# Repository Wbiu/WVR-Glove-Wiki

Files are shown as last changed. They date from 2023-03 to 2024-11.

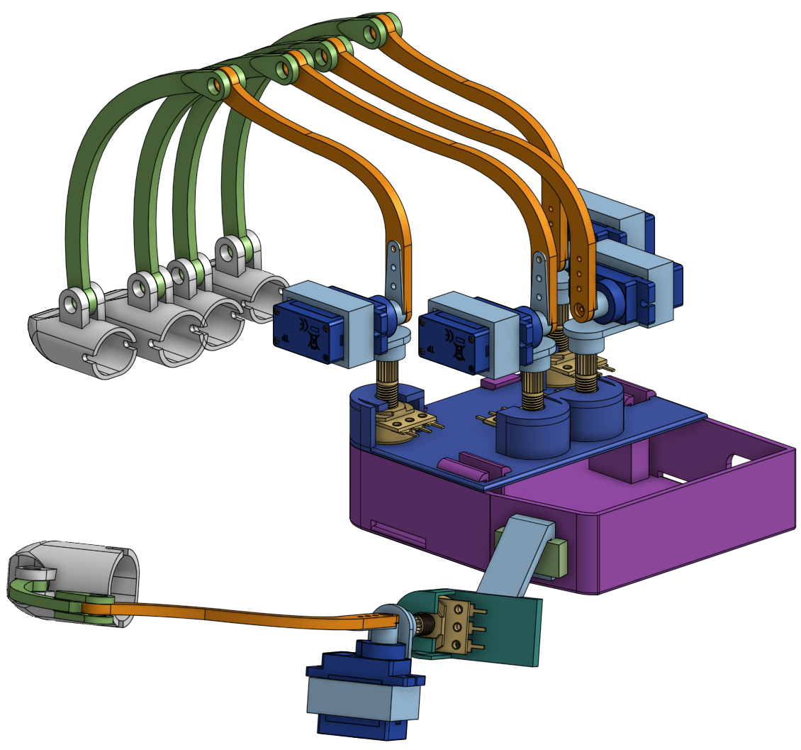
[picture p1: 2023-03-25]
Glove_STL/oneShape_model_v1.PNG

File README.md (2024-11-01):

# WVR Glove Wiki
## Let´s start building the glove
### Things that you will need before we start building.

> **note** : I´m assuming that you have some basic stuff before hand 
> such as soldering equipment, 3D printer and some tools ... <br/>
> Also some knowledge in C++ would help you a bit.

> **info** : for newbies this could be a bit tough. I was thinking about doing a youtube tutorial. For that please vote in [discord](https://discord.gg/FY35dYT8) in the vote chanel, if there is an interest for a video. 

* esp32 (wroom/wrover) Dev-board (I´m recommending that you get 2 of them )
* 1x 9 axis IMU (in this project a BNO055 was used)
* 5x sg90 Servos (this has to be some specific ons. see more in **modding servo**)
* 5x B10K [Potentiometer](https://www.amazon.com/TELESKY-Linear-Potentiometer-Variable-Resistors/dp/B09T32L928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) (also get them with some washer and nuts)
* some prototype pcb board (a 5x7 should be enough) <br/>
* bread board for testing purposes
#### optional stuff , but also recommended to have :
* 5x (10x) jst connector 5 pin both male (5x) and female (5x) (if you don't own any of it a jst tool kit would help you out)
* I also use **TPU** for printing the fingertips.

## Printing the parts
Download the part from [this wiki](https://github.com/Wbiu/WVR-Glove-Wiki) repo.

## Modding SG90 servos
> **note** : This part could be somewhat complicated if you haven't work much in electronics. **But** it's not impossible. So let's go...

First **make sure** you get the right servo. What I mean by that is there are some **internal** differences depending on where you get them. 

What you will need is a servo with **2 chips** in it! <br/>
Next is to look up the part number on google. If google says that it is a **H-Bridge**  or a **H-Bridge motor control** then you are on the right track!  <br/>
In my case the **H-Bridge** is **TC8301**s and sometimes there could also  **TC118**s.

TC8310 servo

Now if we take a look at the data sheet of the **TC8301**. In the data sheet there is an example circuit diagram.
And we can see that pin **2** and **3** are labeled as input **A** and **B**.
With these 2 pins we can control the **speed** and **direction** with a **PWM** signal.  

tc8301 circuit

Here is how we can control the motors **speed** and **direction**. Later on we control these input with a PWM signal.<br/> L = low <br/>
H = high<br/>
TC8301 mode

In theory you can solder on the wires directly on the **TC8301** pins. A wire to INA and also a wire to INB, then also a wire to the middle pin of the potentiometer.
The yellow wire is no longer needed and can be removed.

And now you will have 5 wires attach to your servo. 
* INA wire
* INB wire 
* Potentiometer middle pin
* +VDD
* -GND

In my case I didn't do it that way. I flipped the PCB around and remove the other chip ("servo controller IC"). After some measuring I found out that there are pads connected to the **H-Bridge**. So I connected my wires there. But an additional wire connection is needed.
And of course there should be 5 wires coming out of the servo. 

> **tip** : take a note to your connected wires.
> And make **sure** that you cut a bigger exit for all the wires. 

> **caution!!** : there could be is a small extrusion/tip to prevent the servo from spinning 360°. This needs to be removed!

modded Servo
> **note** : picture is mirrored/flipped <br/>
>Servo Pos = Potentiometer middle pin

## Preparing the ESP32
Get visual studio code and install plattformio.
Download the [firmware](https://github.com/Wbiu/WVR-GLOVE-Firmware) and add it to plattformio.<br/>
PlattformIO : Home>Projects>Add Existing

> **note** : The default serial baud rate in the firmware is set to 250000.<br/>
> This can be changed in src/Properties.h under ``#define BAUDRATE`` 

Now just compile and upload the firmware to the esp32 to the right COM port with a baud rate of 115200. <br/>

> **note** : if you haven't changed the baud rate in the firmware please remember that you need set the baud rate in the serial monitor to 250000.

If you open up a serial monitor it should print out **" initialization error "** because no component are connected at the moment.

## Wiring 
Here is how every thing is wired internally.<br/>
I'm recommending that you prewire every thing on the breadboard first.<br/>
The IMU I'm using is the BNO055 from Adafruit.
internal wiringpng

## Testing
Now let's do some testing before you build the actual glove.
If every thing is connected correctly it should say **" initialize successful "** after boot up and you will get a lot of values that look somewhat like this.<br/>
data_out_esp

And to test whatever the servo has been successfully modded you can send ``120;0;0;0;0`` to the eso32. This will turn on the the **thumb servo**. Or if you send ``-120;0;0;0;0`` then servo will turn the other way around. The larger the value, the faster it becomes. Max value is ``255``. The value for turning off the servo is ``0;0;0;0;0``. 
> **note** : **thumb** ; **index** ; **middle** ; **ring** ; **pinky**

You can also hold the position reading process with ```#hold``` then the output should pause.
To continue just send ```#continue``` then the position reading process should resume.

## Configuration
To configure the glove I've wrote an aplicatoion for this.
See [here](https://github.com/Wbiu/WVR-Glove-Configurator).

## Additional connection

To keep every thing nice and tight. I made a adapter board with JSTs, to put on top of the esp32.
esp_adapterboard
serco_jst

## Final look

oneShape_model_v1

## Unreal Engine testing ground
After all the hard work let's test the glove in [Unreal Engine](https://github.com/Wbiu/WVR-Glove-Unreal-Engine-5.1-testing-ground) which I've built from the ground for this project. 
UE5 Greif Test _Trim

## Support
 If you want you can join my [discord](https://discord.gg/TnM6WXtwfb) server if there is any issues or questions.

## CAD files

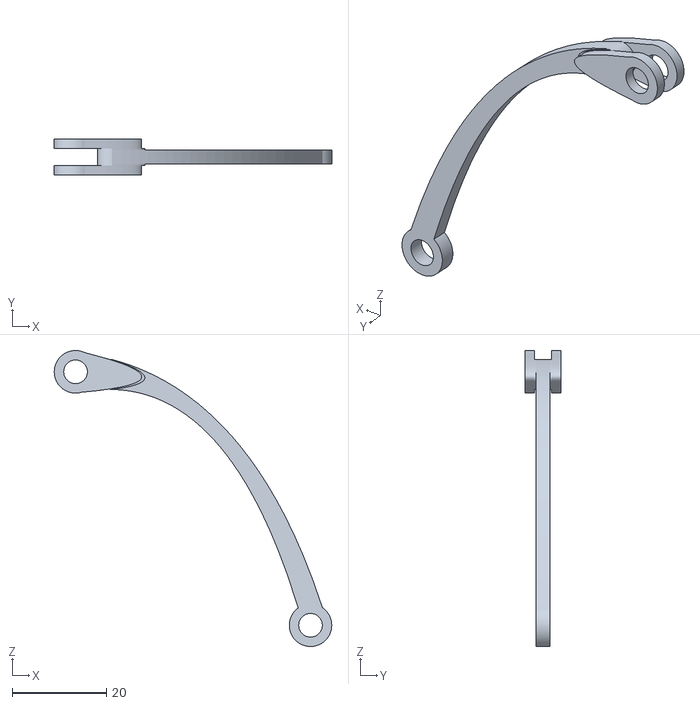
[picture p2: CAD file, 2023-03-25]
Glove_STL/finger arms/Finger arm thumb.stl
58.8 x 7.60 x 62.7

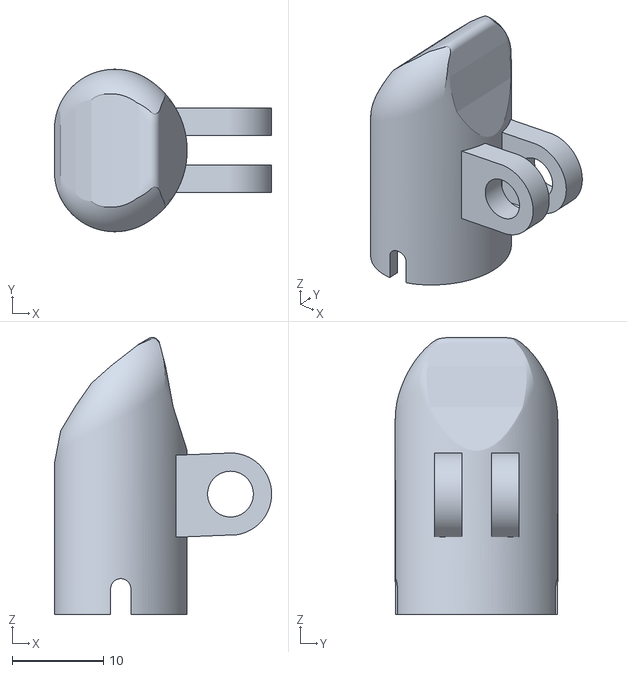
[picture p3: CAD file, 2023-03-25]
Glove_STL/finger tips size/index and ring/Index-Ring Tip_S.stl
23.8 x 17.8 x 30.3

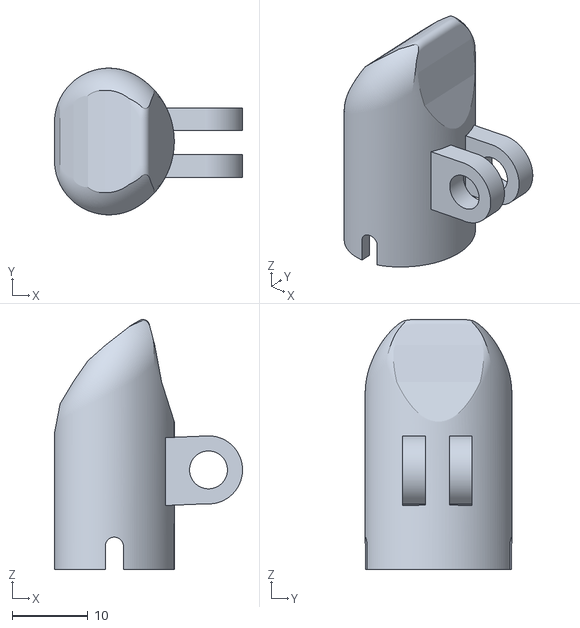
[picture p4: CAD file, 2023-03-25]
Glove_STL/finger tips size/middle/Middle Tip_S.stl
24.9 x 19.4 x 33.0

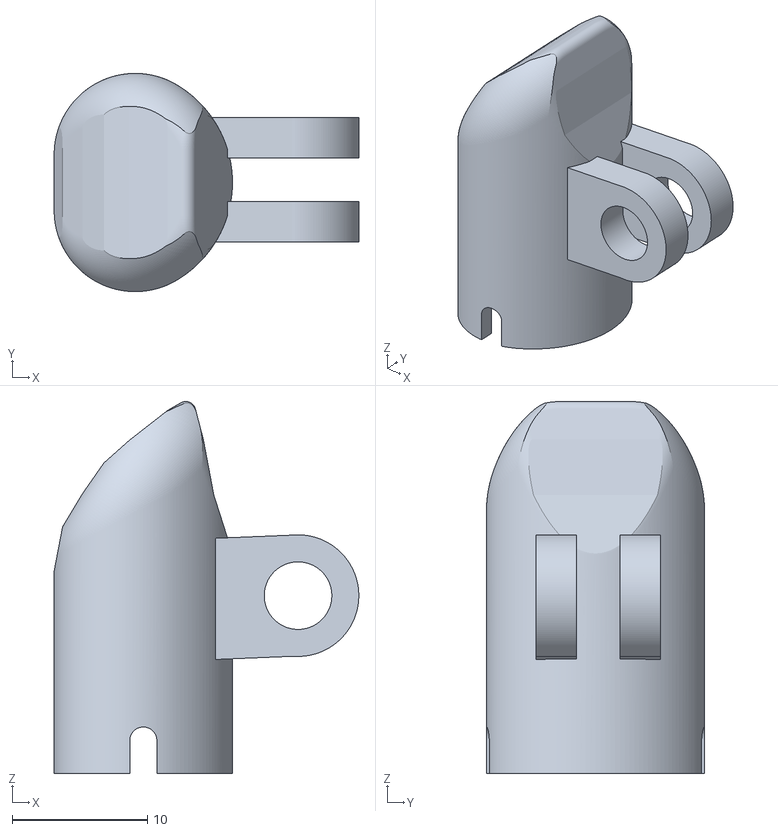
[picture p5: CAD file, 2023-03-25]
Glove_STL/finger tips size/pinky/Pinky Tip_S.stl
22.6 x 16.2 x 27.5

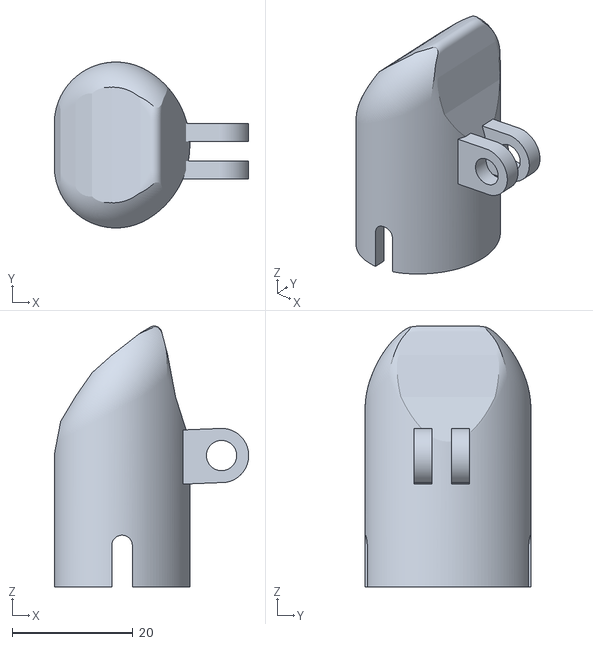
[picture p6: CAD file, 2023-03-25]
Glove_STL/finger tips size/thumb/Thumb Tip_M.stl
32.2 x 27.5 x 43.2

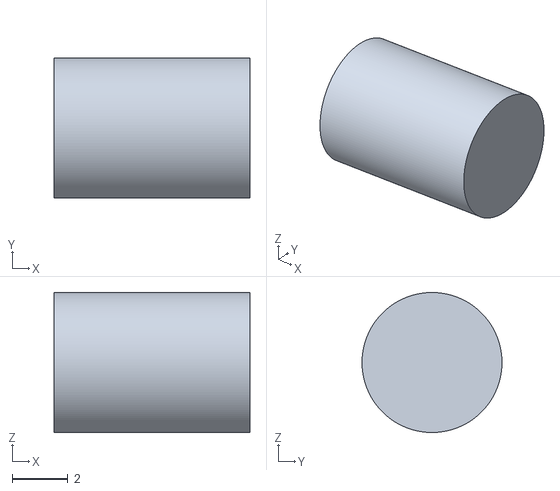
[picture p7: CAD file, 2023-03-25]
Glove_STL/plug.stl
7.00 x 5.00 x 5.00

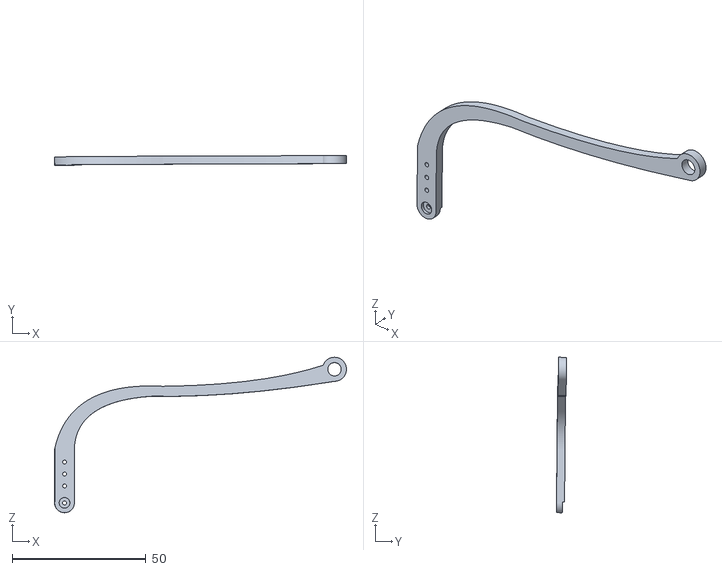
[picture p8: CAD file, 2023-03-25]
Glove_STL/servo arms/Servo arm middle.stl
109.3 x 3.79 x 58.2

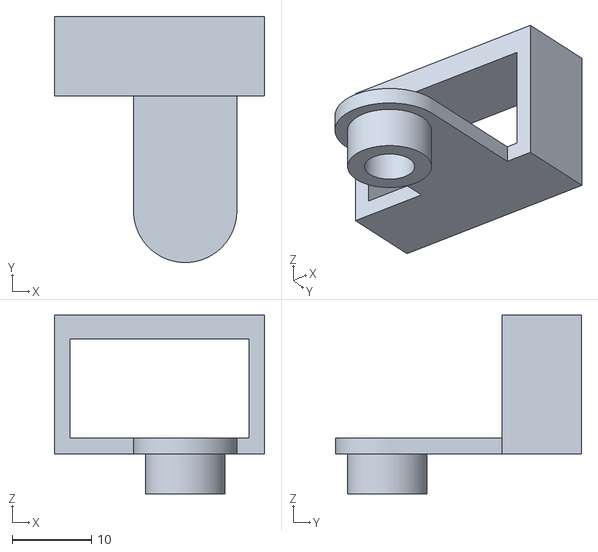
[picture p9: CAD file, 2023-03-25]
Glove_STL/servo holders/Servo holder right half.stl
26.5 x 31.0 x 22.5

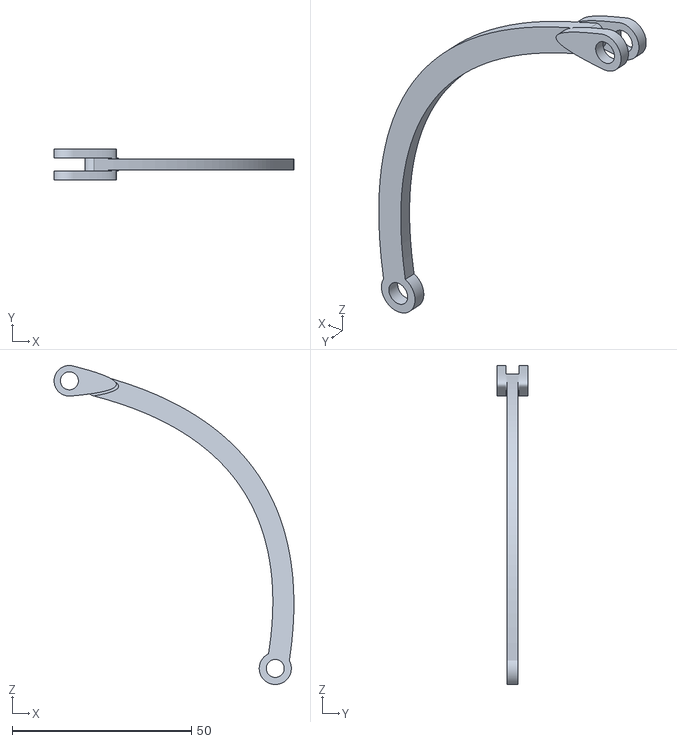
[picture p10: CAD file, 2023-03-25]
Glove_STL/finger arms/Finger arm all.stl
66.9 x 8.60 x 88.9

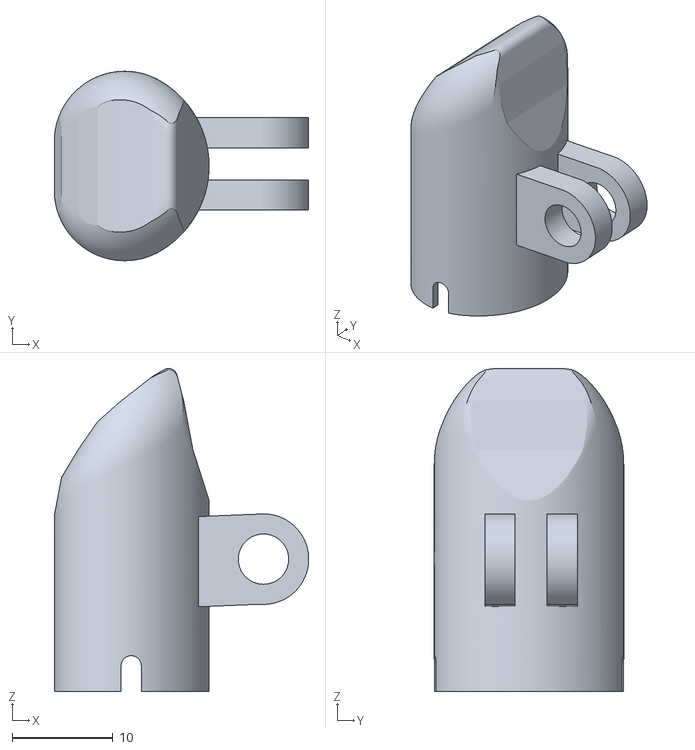
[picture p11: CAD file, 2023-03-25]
Glove_STL/finger tips size/index and ring/Index-Ring Tip_M.stl
25.3 x 18.8 x 32.1

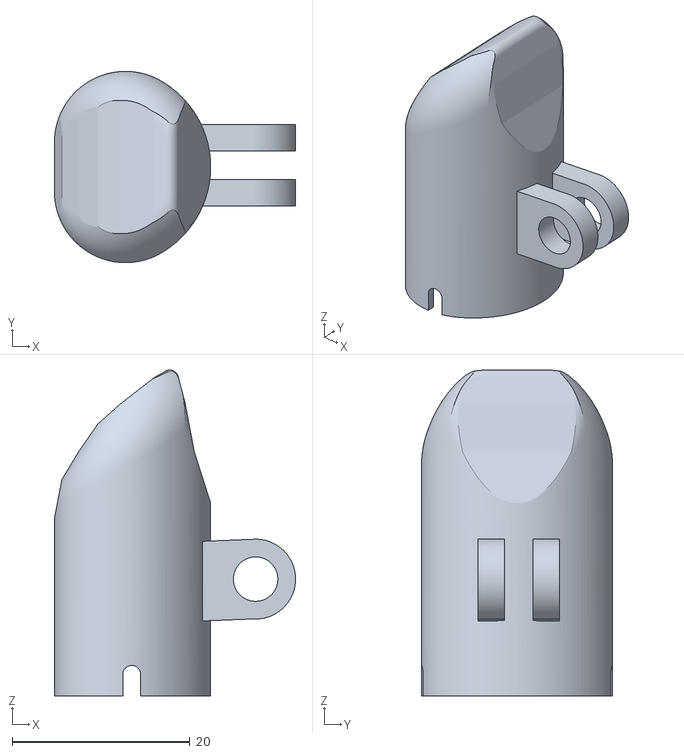
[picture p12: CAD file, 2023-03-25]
Glove_STL/finger tips size/pinky/Pinky Tip_L.stl
27.2 x 21.5 x 36.7

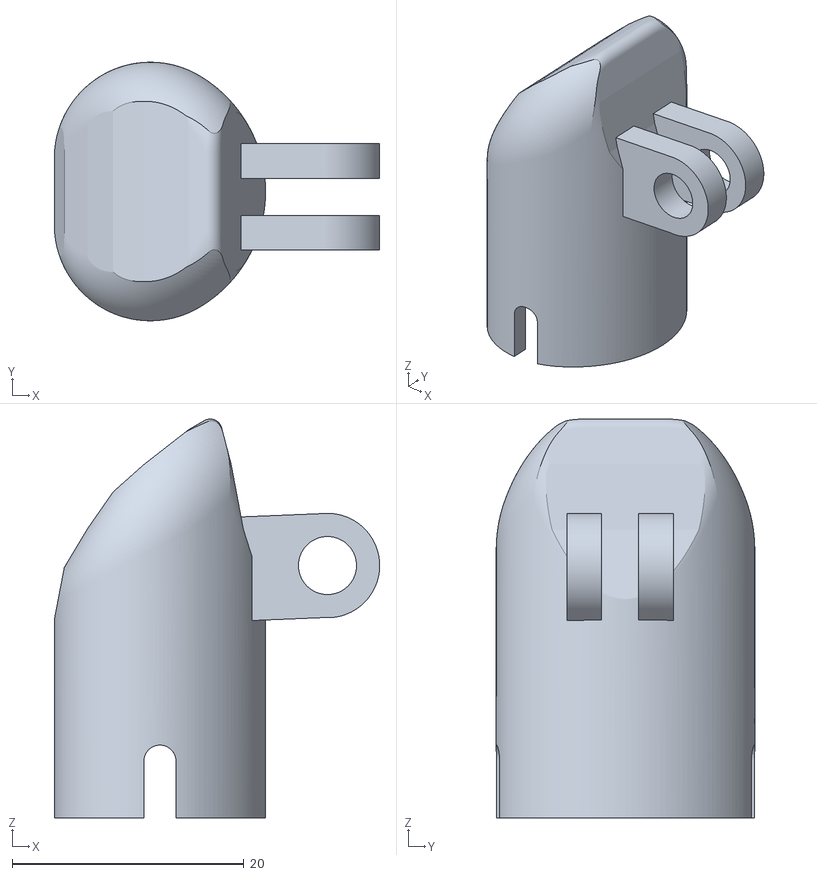
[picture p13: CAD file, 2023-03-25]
Glove_STL/finger tips size/thumb/Thumb Tip_S.stl
28.1 x 22.3 x 34.4

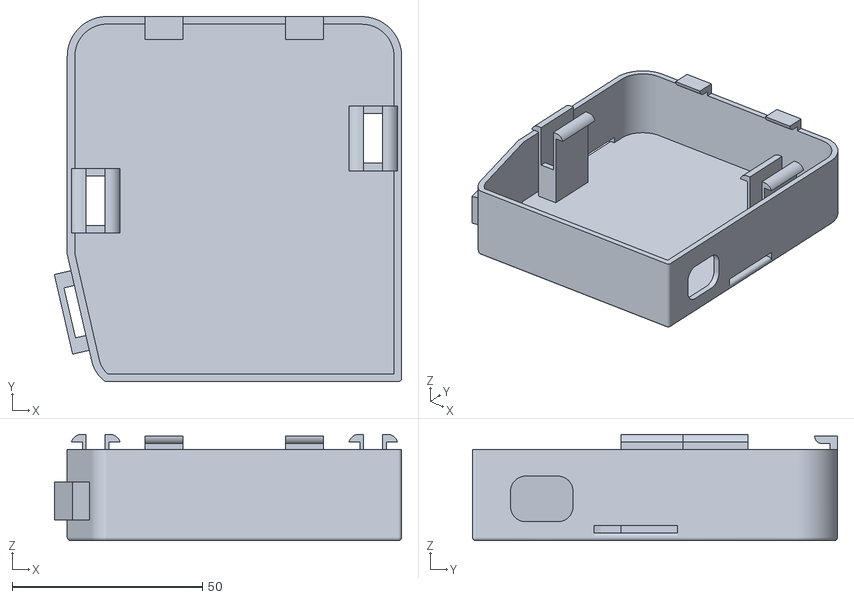
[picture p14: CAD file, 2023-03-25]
Glove_STL/Hand cover amb.stl
91.4 x 96.0 x 28.0

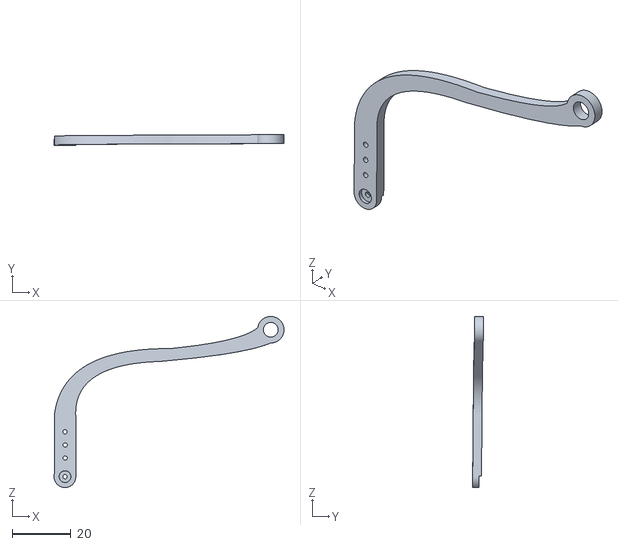
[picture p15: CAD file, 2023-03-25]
Glove_STL/servo arms/Servo arm index.stl
78.3 x 3.71 x 58.2

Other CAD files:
Glove_STL/servo holders/Servo holder left and thunmb half.stl
Glove_STL/finger tips size/index and ring/Index-Ring Tip_L.stl
Glove_STL/finger tips size/pinky/Pinky Tip_M.stl
Glove_STL/finger tips size/thumb/Thumb Tip_L.stl
Glove_STL/Handcover Top.stl
Glove_STL/Thumb holder amb.stl
Glove_STL/servo arms/Servo arm pinky.stl
Glove_STL/servo arms/Servo arm ring.stl
Glove_STL/servo arms/Servo arm thumb.stl
